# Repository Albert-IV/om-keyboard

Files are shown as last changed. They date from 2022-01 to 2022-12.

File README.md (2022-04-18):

# Om Keyboard

Right now I'm iterating on a 34 key split that uses MX spacing horiontally and choc spacing vertically.  Uses the splay from the Absolem keyboard and the lowered thumb keys of the Draculad.  

# Photos
## Rev 1 Photos

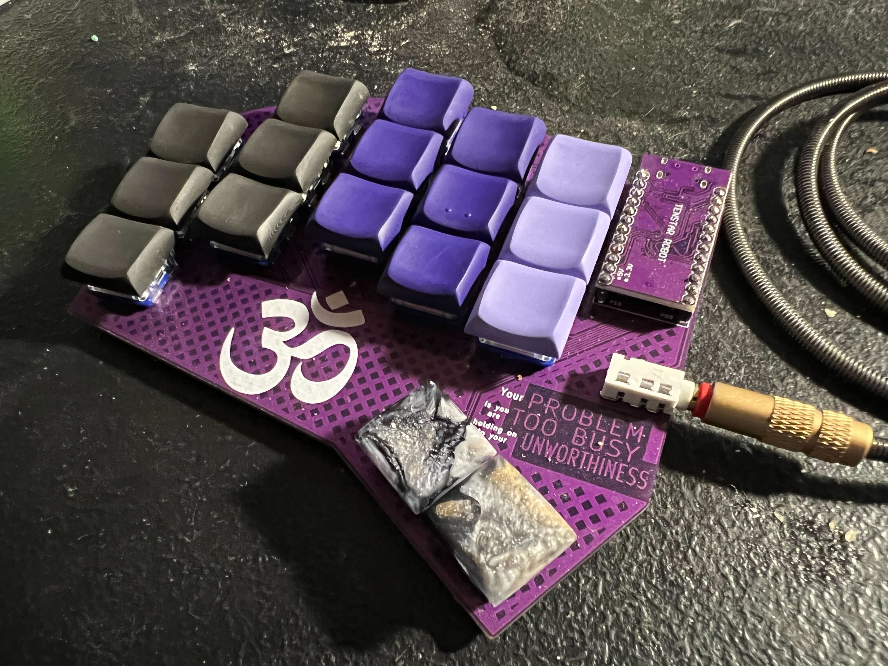
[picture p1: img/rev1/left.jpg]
Left Side


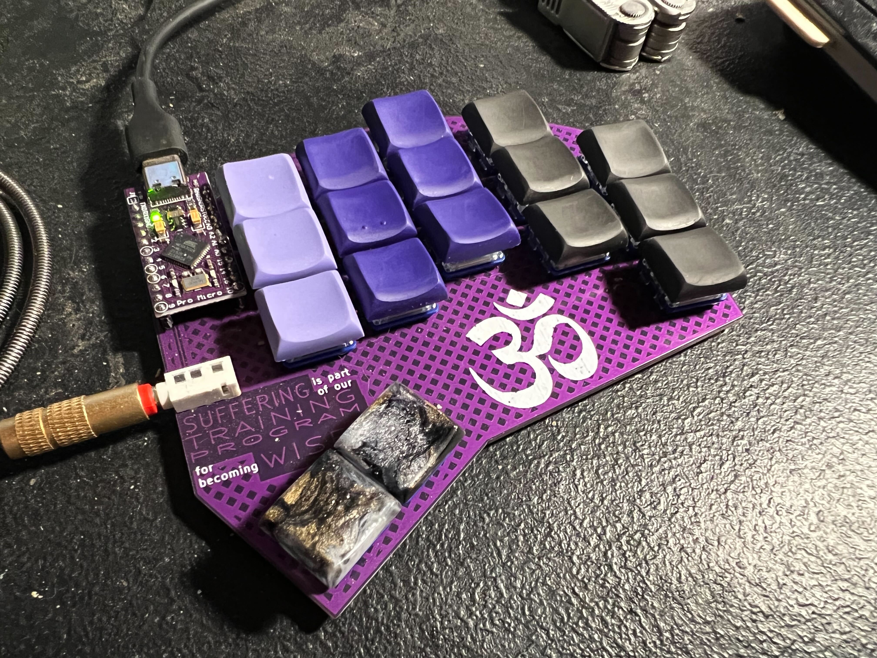
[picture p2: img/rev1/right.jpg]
Right Side


## Rev 0 Photos

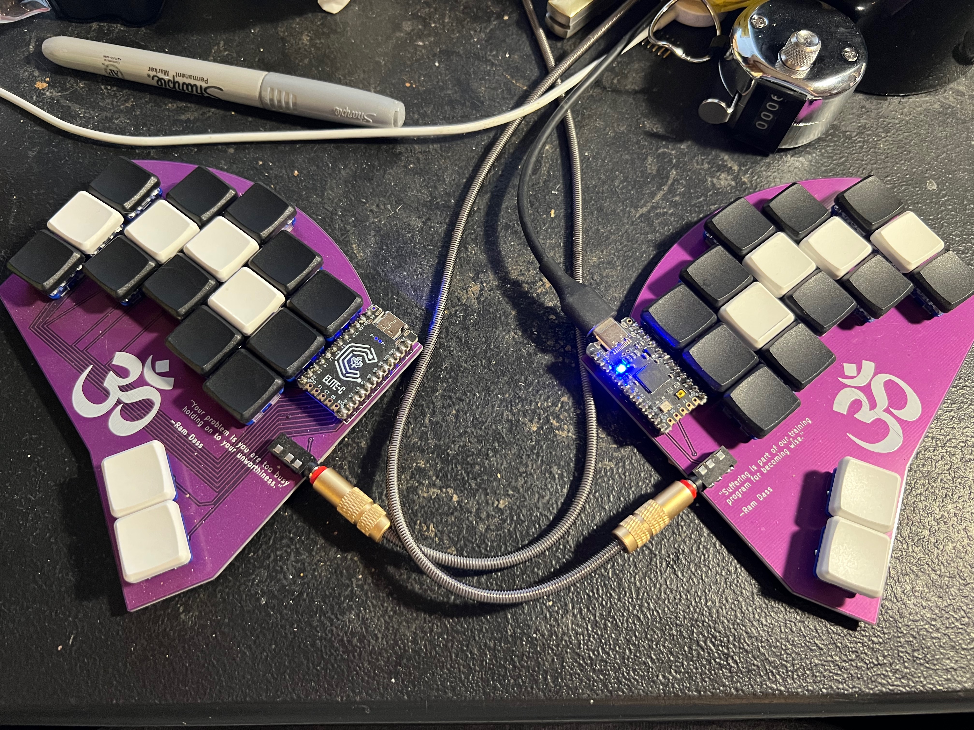
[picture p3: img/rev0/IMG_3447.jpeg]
MBK Build


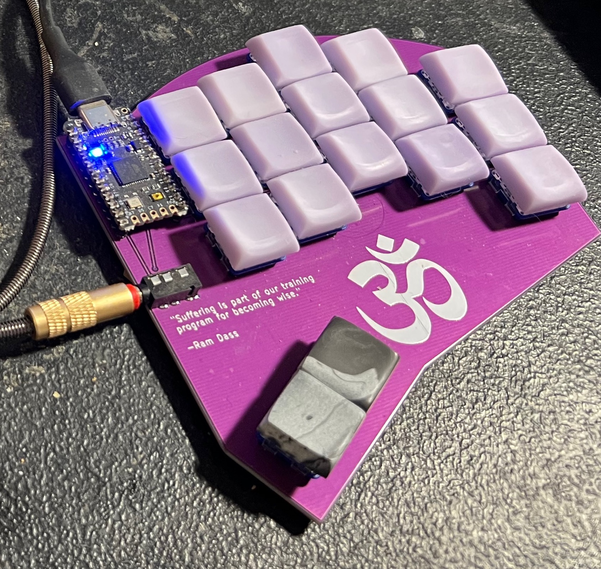
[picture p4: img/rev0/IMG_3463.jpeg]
Build with purple CS caps


# Notes

## Rev 1
Rev 0 was a pretty good success, though there are other tweaks that need to be made.  

Pinkies were not staggered enough I've found after trying out the Osprette keyboard.  The Osprette features a home pinky location that's equal to the bottom key of the ring finger and feels really comfortable / right.  Attempted to do the same for the pointer finger keys, however with such advanced stagger could not comfortably reach the bottom inner column keys.  30-key keyboards maybe have a point?

Additionally wanted to change the location of the ring finger as well.  Right now my ring finger naturally wants to rest on the outer ridge of the ring finger home key.  To compensate, I moved the key about a third of a U over, increasing the spave to hopefully feel correct. Looking at the spacing, this begs for splay, but will save this for the next iteration for now.  

Lastly I wanted to change the thumbs a _touch_ though not a ton as they felt pretty good.  I do feel like they may be a little low, but possibly not.  With MBK profile keycaps the thumbs weren't ultra comfortable, but once moved to CS felt great.  Actuating the key leverages the top joint of your thumb rather than the thumb tip, which for some may be optimal.  I chew my fingers a lot, so avoiding having to actuate with the side of my thumb nail where there may be hangnails is a feature, not a bug.

I still did move the thumbs up a touch.  Just a smidge.  It's hard to tell, as I had a key incorrectly placed inside my Ergogen config that made thumb positioning unreliable and reliant on other keys locations.  Future iterations will have a corrected config which will be rock solid, but for now I eyeballed positioning and hope it works out.  I do want to play with thumb rotation, but I'm unsure how to measure that.  When using arm rests my thumb arc looks one way, and while resting on the table the thumbs arc in a slightly different line.  May want to use some combination of the two?  Not sure.

Next iteration will leverage cardboard cutouts, so that I can put in switches and test drive on next layout iteration to fully dial in positioning.  Overall rev0 did feel comfortable, but not 100% perfect. I may play with an Osprette-like pinky cluster in the future, bumping the key count to 36 keys temporarily.

## Rev 0
Initial prototype using 34 keys, choc spacing vertically and MX spacing horizontally with a deep thumb a la Draculad and a touch of splay stolen from the Absolum.

PCB's were ordered from JLCPCB and built roughly Feb 23-24th 2022.  Used as a daily driver for about a month before making iterations for Rev 1

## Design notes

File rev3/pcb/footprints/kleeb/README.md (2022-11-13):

# Kleeb

This is a collection of the Kicad symbols, footprints and 3D models useful in keyboard creation other than normal mechanical switches and the ones included in Kicad's standard library, all in 6.0 format. I didn't create all of them, and some come from either other people on Discord, or from other online resources that isn't in a Git tree. Putting them in a centralized place means it's easier for people to use, distribute*, and compare, and changes can be made in a clearer way. I'll try to list the sources down below, but due to the nature of the sources they maybe incorrect/missing. If you have a problem with how I'm using/distributing them please let me know.

## License

Those directly created by me is licensed under MIT. Those came from Discord are technically in a grey zone, as they are shared without a (explicit) license. For those that came from other sources, the original license should be used. I do not intend to claim ownership over them, and they are here so they can be easily included in future projects.

## Symbols

### `ic`

- `MCP23S08`: From @petejohanson, converted to 6.0. 8-bit SPI bidirectional I/O expander, missing from Kicad libray
- `MT25QL128ABA1ESE`: created by me. 128Mib/16MiB QSPI NOR flash
- `CMM4030D`: I2S microphone
- `TMP117`: I2C high accuracy temperature sensor
- `IS31FL3729`: 16x8 or 15x9 I2C LED matrix driver
- `MAX98357A`: I2S DAC amplifier

### `display`

- `eink-128x80`: created by me. [128x80 Eink from waveshare](https://www.waveshare.com/product/displays/1.02inch-e-paper-module.htm)
- `ILI9341`: created by me. ILI9341 module
- `LCD2.2"`: created by me. [2.2 in TFT LCD module from Adafruit](https://www.adafruit.com/product/1480)
- `OLED-128x32`: created by me. Classic 128x32 OLED module [Example](https://www.littlekeyboards.com/collections/oled-screens/products/oled-screen)
- `OLED-128x64`: created by me. 128x64 OLED module [Example](https://www.littlekeyboards.com/collections/oled-screens/products/128x64-oled-screen)
- `adafruit-sharp-memory-display`: created by me. [Adafruit 1.3in SHARP memory display module](https://www.adafruit.com/product/3502)
- `adafruit-sharp-memory-display-no-useless`: created by me. Same as above but without non-necessary pins
- `TM022HDH26`: created by me. [2.2in raw SPI TFT LCD module](https://www.aliexpress.com/item/32417585937.html)

### `ic`

- `CMM4030D`, `eTQFP-32_7x7mm_P0.8mm`: created by me from datasheet

### `switch`

- `SKRHA`: created by me. [5-way joystick from Alps](https://www.mouser.com/ProductDetail/Alps-Alpine/SKRHAAE010?qs=6EGMNY9ZYDQQG43X8RE8sg%3D%3D)
- `diode-choc`: created by me. Originally taken from [@PJE66](https://github.com/PJE66), but with some of the pins hidden as they are not needed for external connections. Even though they are still 2 pin "components", the diode is included for clarity in the schematics, and should be used with the autogenerated choc footprints.

### `mcu`

- `holyiot-18010`: From someone else on Discord, but modified by me. [Holyiot 18010 nRF52840 BLE module](https://www.aliexpress.com/i/32868002366.html)
- `holyiot-18010-no-underside`: Same as above, but without underside pads
- `xiao`: created by me, merged from the `xiao` repo. The [Xiao controller](https://www.seeedstudio.com/Seeeduino-XIAO-Arduino-Microcontroller-SAMD21-Cortex-M0+-p-4426.html) from Seeed Studio.
- `xiao-ble`: Same as above. The [Xiao BLE controller](https://www.seeedstudio.com/Seeed-XIAO-BLE-nRF52840-p-5201.html) from Seeed Studio.
- `rp2040-zero`: created by me. The [RP2040 Zero controller](https://www.waveshare.com/rp2040-zero.htm) by WaveShare.
- `ms88sf3-nrf52840`, `ms88sf3-nrf52840-split`: From @Kurtis on Discord, who used a split symbol. I merged the ground pins and merged the units for the symbols, and corrected the footprint according to the datasheet, also making the keepout 5mm wide.

## Footprints

### `display`

- `LCD2.2in`: created by me.
- `OLED-128x32`: created by me.
- `OLED-128x32-cutout`: Same as above, but show the display area. Data came from `@rain` on Discord
- `OLED-128x32-double-sided`: Same as above, but has jumpers on both sides allowing the OLED to be installed on both sides. The jumpers on the reverse side of the display are to be soldered.
- `OLED-128x64`: created by me.
- `TM022HDH26`: created by me. Holes follow the positions on datasheet, pads are measured data
- `TM022HDH26_back`: Same as above, but pads are on the different side of PCB
- `adafruit-sharp-memory-display-1.3in`: From someone on Discord, modified by me
- `adafruit-sharp-memory-display-1.3in-no-mounting`: Same as above
- `adafruit-sharp-memory-display-1.3in-no-mounting-no-useless`: Same as above

### `mcu`

- `holyiot-18010`: Probably from someone on Discord, modified by me. [Holyiot 18010 nRF52840 BLE module](https://www.aliexpress.com/i/32868002366.html)
- `holyiot-18010-no-underside`: Same as above
- `xiao-smd`: created by me, merged from the `xiao` repo. The Xiao controller with SMD pads, with throughole pads for the 4 underside pads.
- `xiao-tht`: Same as above. The Xiao controller with THT pads, with throughole pads for the 4 underside pads.
- `xiao-ble-smd`: Same as above. The Xiao BLE controller with SMD pads, with throughole pads for the 4 pads under USB-C connector, 2 battery pads, and 2 NFC pads.
- `xiao-ble-tht`: Same as above. The Xiao BLE controller with THT pads, with throughole pads for the 4 pads under USB-C connector, 2 battery pads, and 2 NFC pads.
- `xiao-ble-tht-cutout`: Same as above. The Xiao BLE controller with THT pads, with throughole pads for the 4 pads under USB-C connector, 2 battery pads, and 2 NFC pads, except there are cutouts around the underside pads, so that one can cut around the pads making it easier to solder those pads.
- `rp2040-zero-smd`: created by me. The RP2040 Zero controller by WaveShare, with SMD pads and a cutout for the MCU itself.
- `rp2040-zero-tht`: Same as above. The RP2040 Zero controller, with THT pads and a cutout for the MCU itself.
- `rp2040-zero-smd-pads` and `rp2040-zero-tht-pads`: ___Experimental!___ Same as above, plus throughole pads to solder underside pads.
- `rp2040-zero-smd-pads-cutout` and `rp2040-zero-tht-pads-cutout`: ___Experimental!___ Same as above, but the pads can be made into castellated ones by cutting through the pads?

### `misc`

- `BA1AAAPC`: [From Digikey](https://www.digikey.com/en/products/detail/mpd-memory-protection-devices/BA1AAAPC/8119216). Low profile AAA battery holder
- `auklet-cover-mount`: created by me. Cover mounting positions for the Auklet steno board
- `auklet-mount`: created by me. Bottom screw hole mounting positions for the Auklet steno board
- `batwings`: created by me. The original batwings logo converted from some picture on the web
- `crides-pos`: created by me. The logo for `crides`
- `crides-neg`: Same as above, but inverted
- `debug-port`: created by me. For use with pogo pin clamp for SWD debug
- `debug-port-single-side`: Same as above, but only top side has solder mask
- `embedded`: created by me. The embedded steno logo
- `hirose-df30fb-20ds-0.4v(82)`: probably from Digikey
- `CMS1609`: created by me from datasheet
- `molex-503182-1852`: probably from DigiKey

### `switch`

- `SKRHA-boss`: created by me, following datasheet from Alps
- `SKRHA-no-boss`: same as above
- `switch-MSK-12C02-smd`: Not sure where from
- `EVQWGD001`: Fetched from `@darryldh` on Discord, not sure of origin

### `pg1350`, `pg1232` and `pg1425`

These footprints are autogenerated with python scripts cuz I hate hand making all the variants I need for choc. It uses [my fork of kicad-footprint-generator](https://github.com/crides/kicad-footprint-generator). The changes in the generator are basically usability changes for myself, and you'll see why in the diff.

The pg1350 footprint dimensions (i.e. pin sizes & locations) is originally taken from [Keebio](https://github.com/keebio/Keebio-Parts.pretty), the pg1232 ones from [here](https://github.com/tamanishi/Kailh_PG1232), and the pg1425 ones from [Kailh documentation](https://github.com/keyboardio/keyswitch_documentation/blob/master/datasheets/Kailh/CPG142501D02.pdf). They are converted to Python and modifications are added.

The outline on `User.Comments` is the outline of the side tabs, and the one on `User.Drawings` is slightly outside of the outline of the keycap, reflecting the spacing.

All of the footprints are auto generated now. Different letters signify different variations.
- `D`: includes diode in the footprint. It uses choc LED hole for (optional) SOD-123 diode placement, and the internal connections are already made. The center of the footprint is placed on the center of the diode to help with PCBA, and it's meant to be used with the custom symbol signifying that it has a builtin diode; 
- `R`: footprint is reversible. Througholes are included for both sides, another pad is used to connect the duplicated hole, and vias are used inside of the diode pads to connect the diodes on both sides, and silkscreens are duplicated on both sides;

All the following variants are spacing variants, which is useless for most people and I keep it here for my own sake.

- `S`: shorter spacing, only affects the cap outline. To be used with 15mm vertical spacing. This as close vertical as chocs gets without modding the switch itself;
- `SS`: "Super Short": even shorter spacing, only affects the cap outline. To be used with 13.5mm vertical spacing. This as close vertical as choc minis (pg1232) gets without modding the switch itself;
- `L` & `R`: only when used with `SS`; off centered spacing for use with same finger double column (e.g. most commonly the 2 columns for index finger, or columns for pinky).
- `N`: only when used with `SS`; as narrow as possible (14.5mm; or is the intersection of the `L` and `R` variants)

## Models

- `adafruit-sharp-memory-display`: Obtained from @petejohanson on Discord, not sure of creator
- `adafruit-sharp-memory-display-no-mounting`: As above, but edited to cut off mounting screw holes
- `BA1AAAPC`: [From Digikey](https://www.digikey.com/en/products/detail/mpd-memory-protection-devices/BA1AAAPC/8119216). Low profile AAA battery holder
- `holyiot-18010`: From `@darryldh` on Discord
- `hro-type-c-31-m-12`: Not sure of source; I probably got it on Discord
- `MBK-1u`: [From `@darryldh` on Thingiverse](https://www.thingiverse.com/thing:4564253)
- `SKRHAD`: [From Alps](https://tech.alpsalpine.com/prod/e/html/multicontrol/switch/skrh/skrhace010.html)
- `OLED-128x32`: Not sure from where. Model for the 128x32 OLED displays
- `TF31-12S-0.5SH`: Not sure from where exactly, should be a manufactorer model. 0.5mm pitched 12pin FPC ZIF socket
- `JST-PH-S2B-R`: [From SnapEDA on Digikey](https://www.digikey.com/short/p1d9b87m). JST PH SMD 2pin connector, commonly used for batteries. [Product on Adafruit](https://www.adafruit.com/product/1769)
- `pg1350`, `pg1350-mbk`, `pg1232`, `pg1232-mbk`: created by me. pg1350 and pg1232 choc switch models with MBK 1u keycaps. The pg1350 model is taken directly from [here](https://grabcad.com/library/kailh-choc-low-profile-switch-1), and the MBK model from [here](https://www.thingiverse.com/thing:4564253/files). The pg1232 model is made by me through cutting and rejoining pieces of the pg1350 model, which should immitate the general model but is otherwise very janky. The joint choc and MBK models are simply the combinations of the switch models and the MBK model.
- `rp2040-zero`: From the low pro Discord from `@gerrycave` from WaveShare. _Giant_ model of the RP2040-Zero, recentered by me through FreeCAD.
- `EVQWGD001`: A copy of <https://grabcad.com/library/panasonic-evqwgd001-encoder-1#!>. Doesn't seem to match footprint
- `TM035035`: From @freznel on Discord, originated from Cirque.

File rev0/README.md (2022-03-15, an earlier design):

Initially this board started off as a repo called cockamamie before finding a theme.  This is why all the files are named this way.

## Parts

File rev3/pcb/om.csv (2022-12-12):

Source: | /Users/alberte/personal/om-keyboard/rev3/pcb/om.kicad_sch
Date: | Tuesday, November 22, 2022 at 09:42:19 PM
Tool: | Eeschema (6.0.8-1)-1
Generator: | /Applications/KiCad/KiCad.app/Contents/SharedSupport/plugins/bom_csv_grouped_by_value.py
Component Count: | 44
Individual Components:
Item | Qty | Reference(s) | Value | LibPart | Footprint | Datasheet | LCSC
 |  | C1 | 1uF | Device:C_Small | Capacitor_SMD:C_0603_1608Metric | ~
 |  | C2 | 1uF | Device:C_Small | Capacitor_SMD:C_0603_1608Metric | ~
 |  | C3 | 4.7n | Device:C_Small | Capacitor_SMD:C_0805_2012Metric | ~
 |  | D1 | D_Schottky | Device:D_Schottky | Diode_SMD:D_SOD-323 | ~
 |  | D2 | Blue LED | Device:LED | LED_SMD:LED_0603_1608Metric | ~
 |  | D3 | Red LED | Device:LED | LED_SMD:LED_0603_1608Metric | ~
 |  | ESD1 | USBLC6-2P6 | Power_Protection:USBLC6-2P6 | Package_TO_SOT_SMD:SOT-666 | https://www.st.com/resource/en/datasheet/usblc6-2.pdf
 |  | J1 | USB_C_Receptacle | Connector:USB_C_Receptacle_USB2.0 | keebio-parts:USB-C-12-Pin-MidMount | https://www.usb.org/sites/default/files/documents/usb_type-c.zip
 |  | J2 | JST-BATT | Connector:Conn_01x02_Female | Connector_JST:JST_PH_S2B-PH-K_1x02_P2.00mm_Horizontal | ~
 |  | J4 | SWD | Connector:Conn_01x04_Female | Connector_PinSocket_2.00mm:PinSocket_1x04_P2.00mm_Vertical | ~
 |  | Q1 | AO3407 | Transistor_FET:AO3401A | Package_TO_SOT_SMD:SOT-23 | http://www.aosmd.com/pdfs/datasheet/AO3401A.pdf
 |  | Q2 | AO3407 | Transistor_FET:AO3401A | Package_TO_SOT_SMD:SOT-23 | http://www.aosmd.com/pdfs/datasheet/AO3401A.pdf
 |  | R1 | 100K | Device:R_Small | Resistor_SMD:R_0603_1608Metric | ~
 |  | R2 | 1M | Device:R_Small | Resistor_SMD:R_0603_1608Metric | ~
 |  | R3 | 2M | Device:R_Small | Resistor_SMD:R_0603_1608Metric | ~
 |  | R4 | 5.1K | Device:R_Small | Resistor_SMD:R_0603_1608Metric | ~
 |  | R5 | 5.1K | Device:R_Small | Resistor_SMD:R_0603_1608Metric | ~
 |  | R6 | 806/820k | Device:R_Small | Resistor_SMD:R_0603_1608Metric | ~
 |  | R7 | 2M | Device:R_Small | Resistor_SMD:R_0603_1608Metric | ~
 |  | R8 | 1K | Device:R_Small | Resistor_SMD:R_0603_1608Metric | ~
 |  | R9 | 1K | Device:R_Small | Resistor_SMD:R_0603_1608Metric | ~
 |  | R10 | 10K | Device:R_Small | Resistor_SMD:R_0603_1608Metric | ~
 |  | R_TACT1 | SW_Push | Switch:SW_Push | om-footprints:SKHLLCA010 | ~
 |  | SW1 | Choc | kleeb-switches:diode-choc | kleeb-pg1350:pg1350-DR
 |  | SW2 | Choc | kleeb-switches:diode-choc | kleeb-pg1350:pg1350-DR
 |  | SW3 | Choc | kleeb-switches:diode-choc | kleeb-pg1350:pg1350-DR
 |  | SW4 | Choc | kleeb-switches:diode-choc | kleeb-pg1350:pg1350-DR
 |  | SW5 | Choc | kleeb-switches:diode-choc | kleeb-pg1350:pg1350-DR
 |  | SW6 | Choc | kleeb-switches:diode-choc | kleeb-pg1350:pg1350-DR
 |  | SW7 | Choc | kleeb-switches:diode-choc | kleeb-pg1350:pg1350-DR
 |  | SW8 | Choc | kleeb-switches:diode-choc | kleeb-pg1350:pg1350-DR
 |  | SW9 | Choc | kleeb-switches:diode-choc | kleeb-pg1350:pg1350-DR
 |  | SW10 | Choc | kleeb-switches:diode-choc | kleeb-pg1350:pg1350-DR
 |  | SW11 | Choc | kleeb-switches:diode-choc | kleeb-pg1350:pg1350-DR
 |  | SW12 | Choc | kleeb-switches:diode-choc | kleeb-pg1350:pg1350-DR
 |  | SW13 | Choc | kleeb-switches:diode-choc | kleeb-pg1350:pg1350-DR
 |  | SW14 | Choc | kleeb-switches:diode-choc | kleeb-pg1350:pg1350-DR
 |  | SW15 | Choc | kleeb-switches:diode-choc | kleeb-pg1350:pg1350-DR
 |  | SW16 | Choc | kleeb-switches:diode-choc | kleeb-pg1350:pg1350-DR
 |  | SW17 | Choc | kleeb-switches:diode-choc | kleeb-pg1350:pg1350-DR
 |  | SW_POW1 | SW_SPDT | Switch:SW_SPDT | Button_Switch_SMD:SW_SPDT_PCM12 | ~
 |  | U1 | nRF52840_holyiot_18010 | kleeb-mcu:holyiot-18010 | kleeb-mcu:holyiot-18010 | http://www.holyiot.com/tp/2019042516322180424.pdf
 |  | U2 | XC6206P LDO | kicad-keyboard-parts:XC6206PxxxMR-Regulator_Linear | Package_TO_SOT_SMD:SOT-23 | https://www.torexsemi.com/file/xc6206/XC6206.pdf | C5446
 |  | U3 | LTC4054ES5-4.2 | Battery_Management:LTC4054ES5-4.2 | Package_TO_SOT_SMD:TSOT-23-5 | https://www.analog.com/media/en/technical-documentation/data-sheets/405442xf.pdf
Collated Components:
Item | Qty | Reference(s) | Value | LibPart | Footprint | Datasheet | LCSC
1 | 2 | C1, C2 | 1uF | Device:C_Small | Capacitor_SMD:C_0603_1608Metric | ~
2 | 1 | C3 | 4.7n | Device:C_Small | Capacitor_SMD:C_0805_2012Metric | ~
3 | 1 | D1 | D_Schottky | Device:D_Schottky | Diode_SMD:D_SOD-323 | ~
4 | 1 | D2 | Blue LED | Device:LED | LED_SMD:LED_0603_1608Metric | ~
5 | 1 | D3 | Red LED | Device:LED | LED_SMD:LED_0603_1608Metric | ~
6 | 1 | ESD1 | USBLC6-2P6 | Power_Protection:USBLC6-2P6 | Package_TO_SOT_SMD:SOT-666 | https://www.st.com/resource/en/datasheet/usblc6-2.pdf
7 | 1 | J1 | USB_C_Receptacle | Connector:USB_C_Receptacle_USB2.0 | keebio-parts:USB-C-12-Pin-MidMount | https://www.usb.org/sites/default/files/documents/usb_type-c.zip
8 | 1 | J2 | JST-BATT | Connector:Conn_01x02_Female | Connector_JST:JST_PH_S2B-PH-K_1x02_P2.00mm_Horizontal | ~
9 | 1 | J4 | SWD | Connector:Conn_01x04_Female | Connector_PinSocket_2.00mm:PinSocket_1x04_P2.00mm_Vertical | ~
10 | 2 | Q1, Q2 | AO3407 | Transistor_FET:AO3401A | Package_TO_SOT_SMD:SOT-23 | http://www.aosmd.com/pdfs/datasheet/AO3401A.pdf
11 | 1 | R1 | 100K | Device:R_Small | Resistor_SMD:R_0603_1608Metric | ~
12 | 1 | R2 | 1M | Device:R_Small | Resistor_SMD:R_0603_1608Metric | ~
13 | 2 | R3, R7 | 2M | Device:R_Small | Resistor_SMD:R_0603_1608Metric | ~
14 | 2 | R4, R5 | 5.1K | Device:R_Small | Resistor_SMD:R_0603_1608Metric | ~
15 | 1 | R6 | 806/820k | Device:R_Small | Resistor_SMD:R_0603_1608Metric | ~
16 | 2 | R8, R9 | 1K | Device:R_Small | Resistor_SMD:R_0603_1608Metric | ~
17 | 1 | R10 | 10K | Device:R_Small | Resistor_SMD:R_0603_1608Metric | ~
18 | 1 | R_TACT1 | SW_Push | Switch:SW_Push | om-footprints:SKHLLCA010 | ~
19 | 17 | SW1, SW2, SW3, SW4, SW5, SW6, SW7, SW8, SW9, SW10, SW11, SW12, SW13, SW14, SW15, SW16, SW17 | Choc | kleeb-switches:diode-choc | kleeb-pg1350:pg1350-DR
20 | 1 | SW_POW1 | SW_SPDT | Switch:SW_SPDT | Button_Switch_SMD:SW_SPDT_PCM12 | ~
21 | 1 | U1 | nRF52840_holyiot_18010 | kleeb-mcu:holyiot-18010 | kleeb-mcu:holyiot-18010 | http://www.holyiot.com/tp/2019042516322180424.pdf
22 | 1 | U2 | XC6206P LDO | kicad-keyboard-parts:XC6206PxxxMR-Regulator_Linear | Package_TO_SOT_SMD:SOT-23 | https://www.torexsemi.com/file/xc6206/XC6206.pdf | C5446
23 | 1 | U3 | LTC4054ES5-4.2 | Battery_Management:LTC4054ES5-4.2 | Package_TO_SOT_SMD:TSOT-23-5 | https://www.analog.com/media/en/technical-documentation/data-sheets/405442xf.pdf

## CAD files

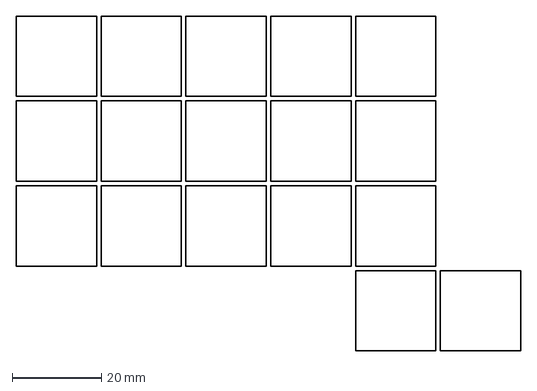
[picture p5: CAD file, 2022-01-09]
output/points/demo.dxf
113.0 x 75.0 mm

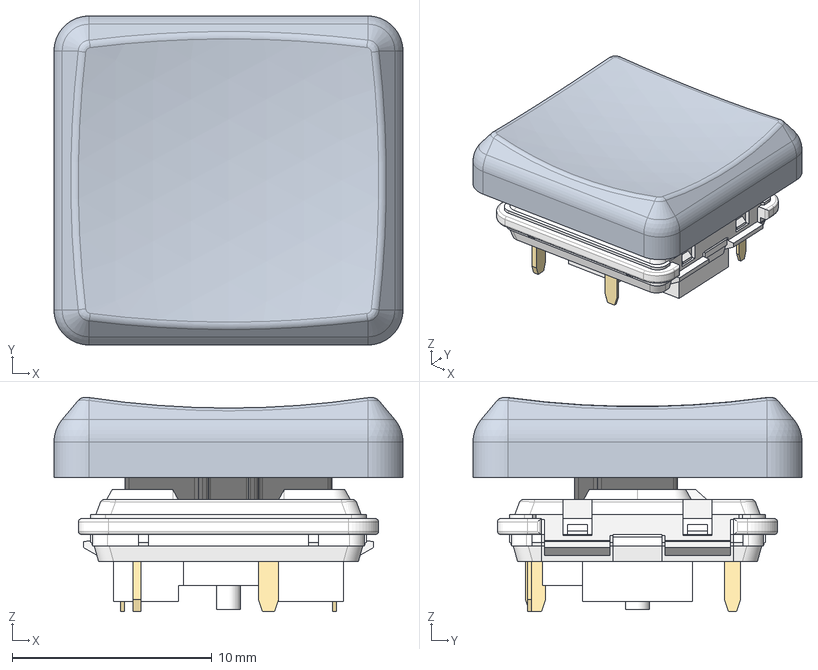
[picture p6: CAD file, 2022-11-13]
rev3/pcb/footprints/kleeb/models/pg1232-mbk.step
17.4 x 16.4 x 10.7 mm
Document x 3
(Unsaved)

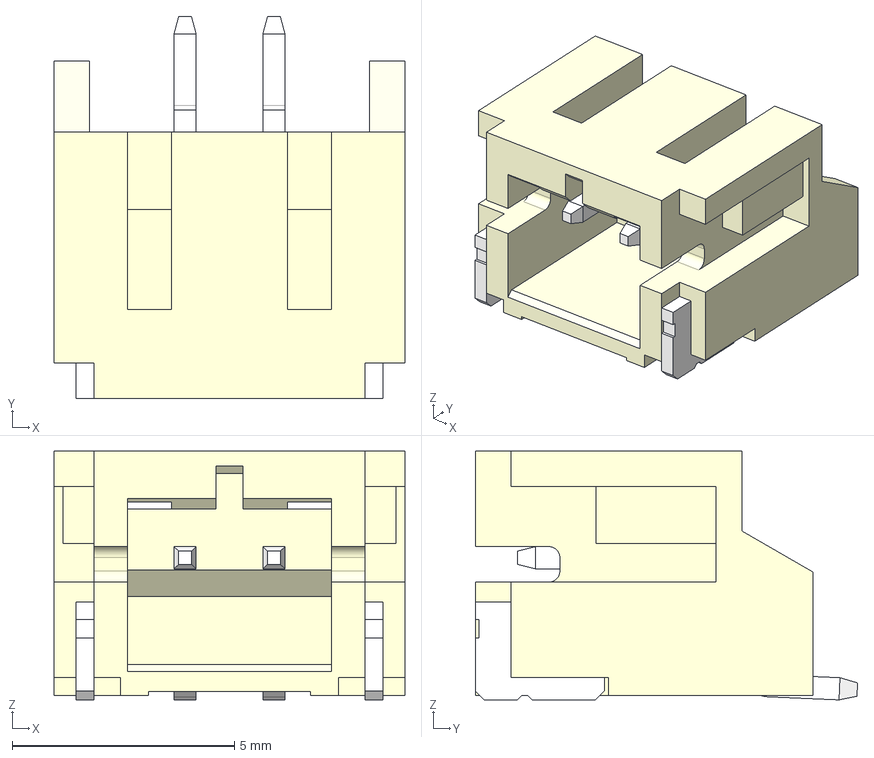
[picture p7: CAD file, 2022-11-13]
rev3/pcb/footprints/kleeb/models/JST-PH-S2B-R.step
7.90 x 8.60 x 5.60 mm

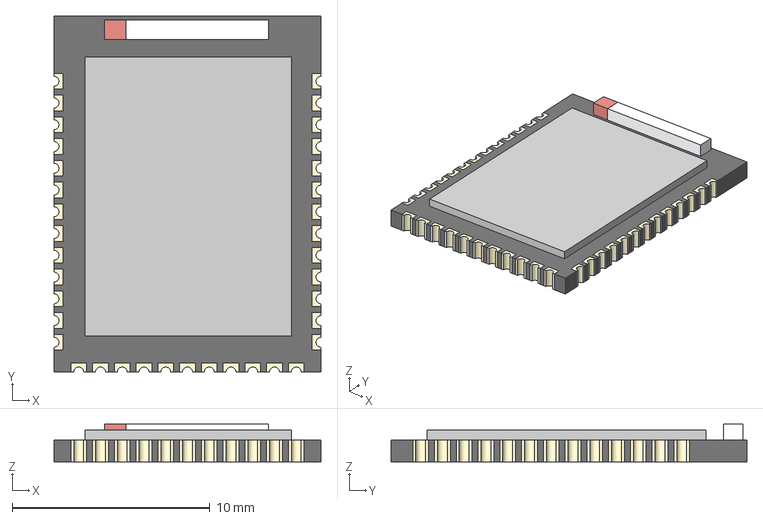
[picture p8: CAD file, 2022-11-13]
rev3/pcb/footprints/kleeb/models/holyiot-18010.step
13.5 x 18.0 x 1.92 mm

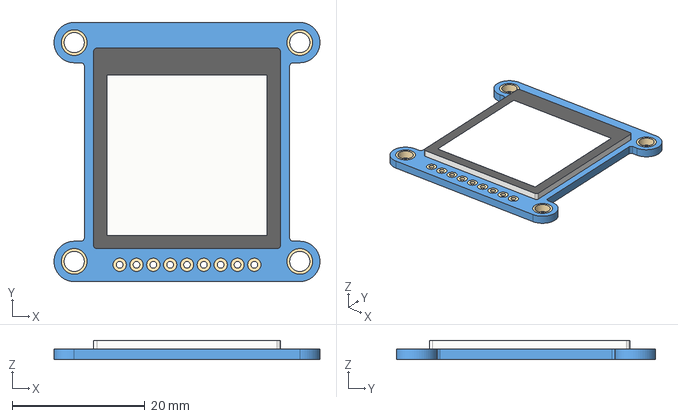
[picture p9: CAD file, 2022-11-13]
rev3/pcb/footprints/kleeb/models/adafruit-sharp-memory-display.step
40.1 x 39.1 x 2.91 mm

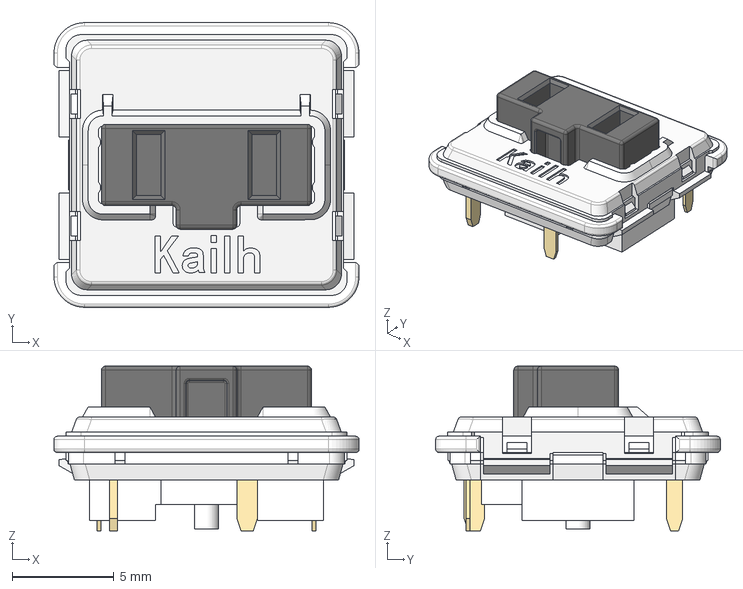
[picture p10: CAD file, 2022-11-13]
rev3/pcb/footprints/kleeb/models/pg1232.step
15.0 x 14.0 x 8.10 mm

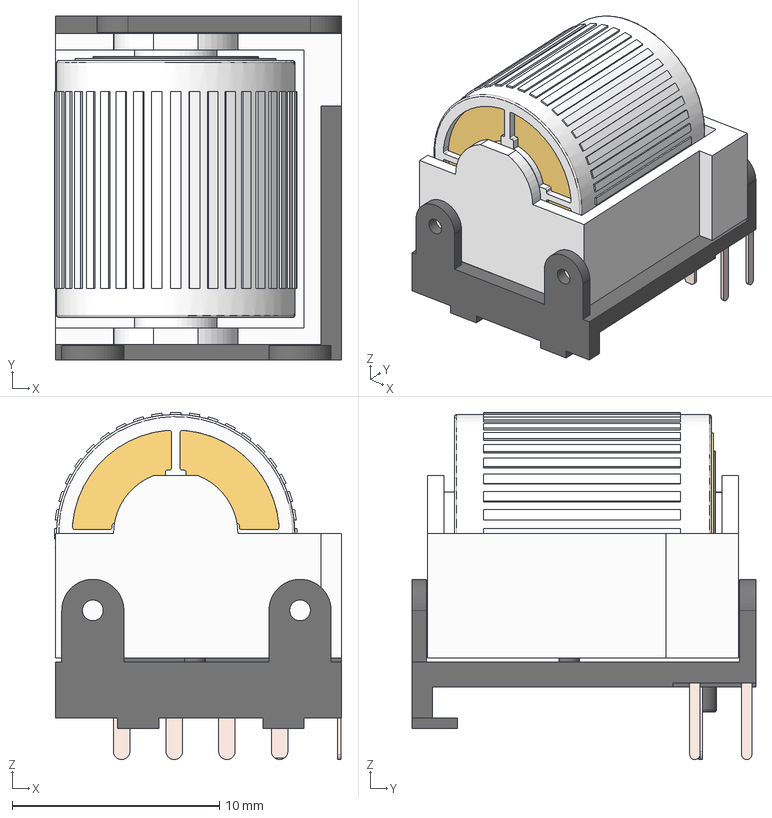
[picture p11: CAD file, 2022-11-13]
rev3/pcb/footprints/kleeb/models/EVQWGD001.step
13.9 x 16.6 x 16.8 mm
Plastic
Barrel in
Cap
Barrel out
Leg (1)
housing
Leg (2)
Leg (3)
Plastic (1)
Leg
Leg (4)
Leg (5)

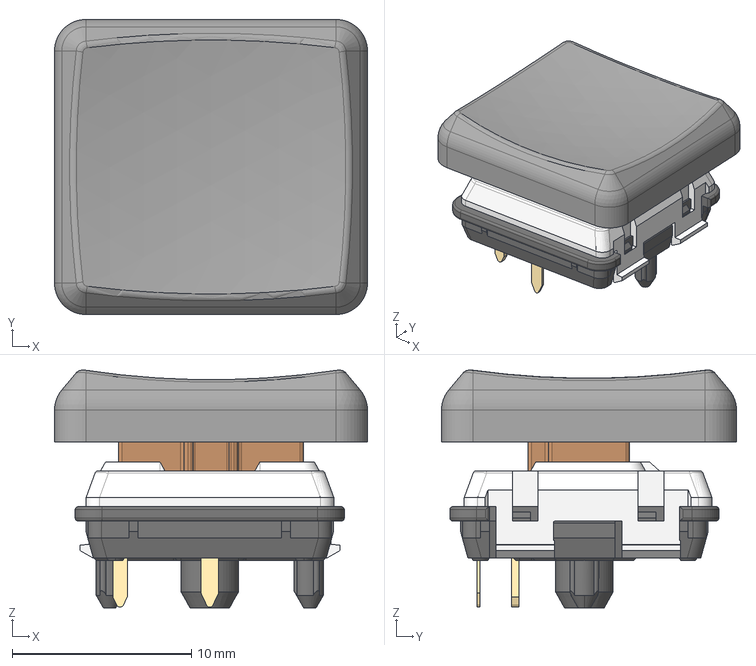
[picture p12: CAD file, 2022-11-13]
rev3/pcb/footprints/kleeb/models/pg1350-mbk.step
17.4 x 16.4 x 13.3 mm
(Unsaved)
Document x 5

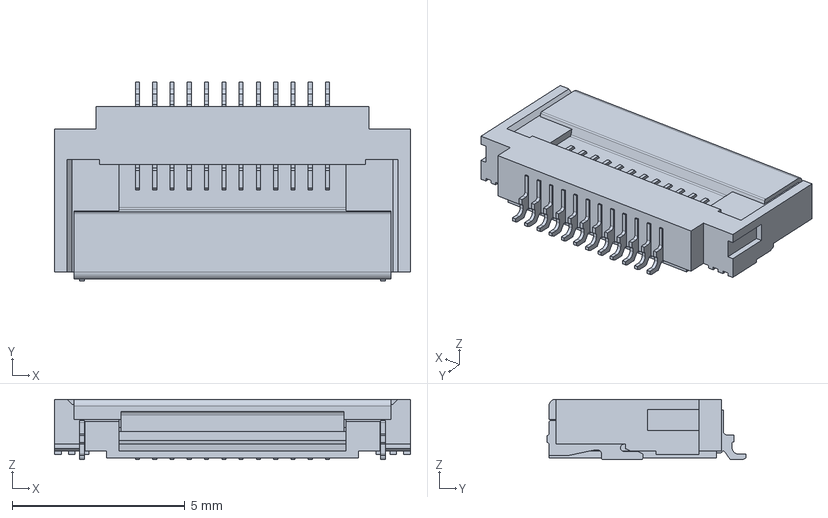
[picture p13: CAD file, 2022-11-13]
rev3/pcb/footprints/kleeb/models/TF31-12S-0.5SH.step
10.3 x 5.75 x 1.75 mm

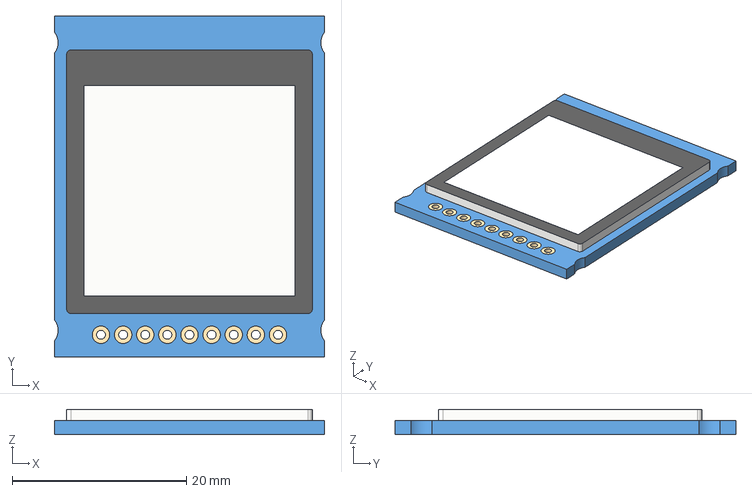
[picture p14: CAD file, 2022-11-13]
rev3/pcb/footprints/kleeb/models/adafruit-sharp-memory-display-no-mounting.step
31.0 x 39.1 x 2.91 mm
Adafruit Sharp Memory Display v4 x 12

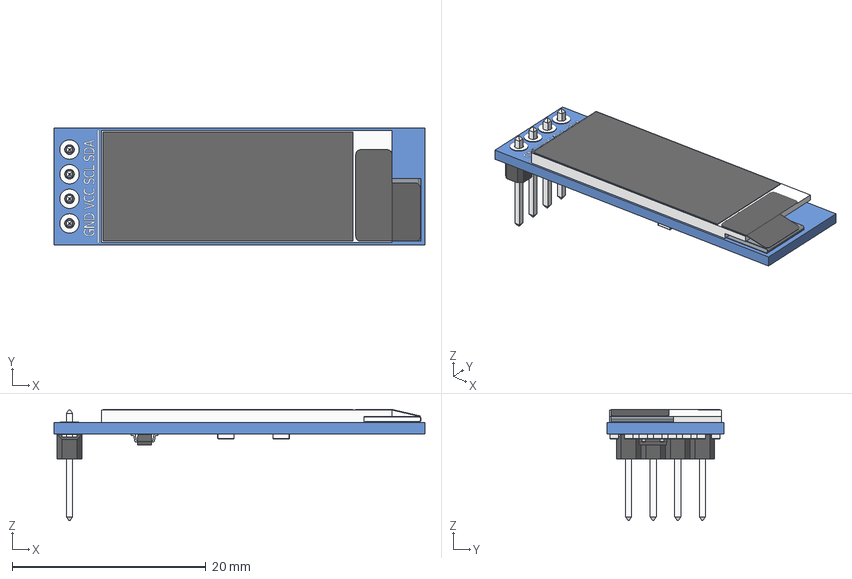
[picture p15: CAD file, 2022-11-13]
rev3/pcb/footprints/kleeb/models/OLED-128x32.step
38.3 x 12.1 x 11.5 mm
OLED_0.91_128x32
Pin Header 4 x 1 TH 2.54mm Pitch
RESC-0603 x 13
2SD0601A

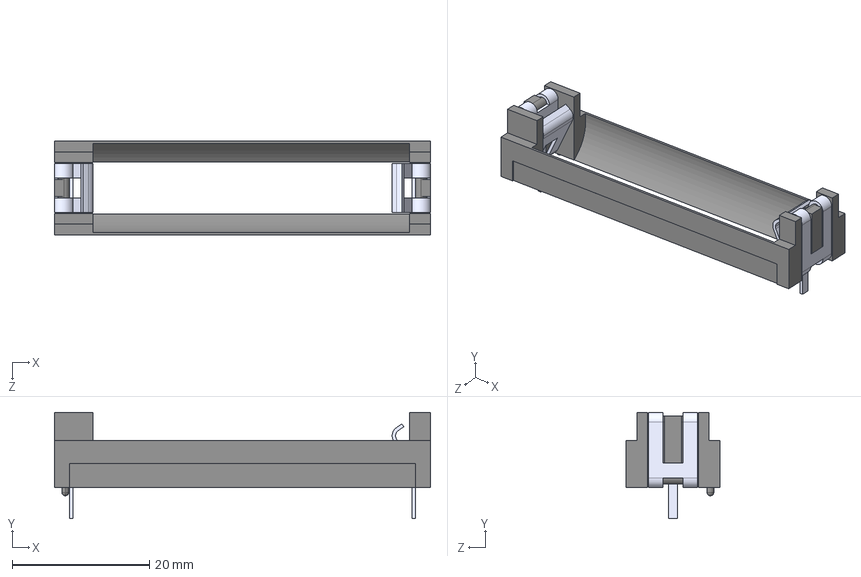
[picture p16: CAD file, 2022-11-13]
rev3/pcb/footprints/kleeb/models/BA1AAAPC.step
54.9 x 15.5 x 13.7 mm

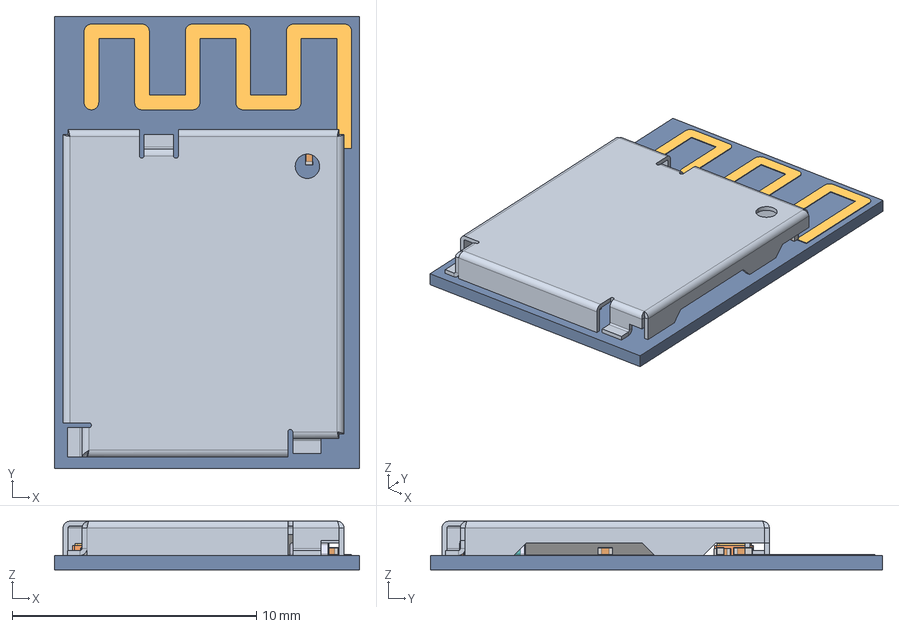
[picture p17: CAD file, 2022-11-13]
rev3/pcb/footprints/kleeb/models/MS88SF3.step
12.5 x 18.5 x 1.99 mm
Board
ANT-2.4G-16
Open_CASCADE_STEP_translator_6.8_9.1
Open_CASCADE_STEP_translator_6.8_9.2.1
pinShape x 184
2012crystal
epson2016
88sf3190624

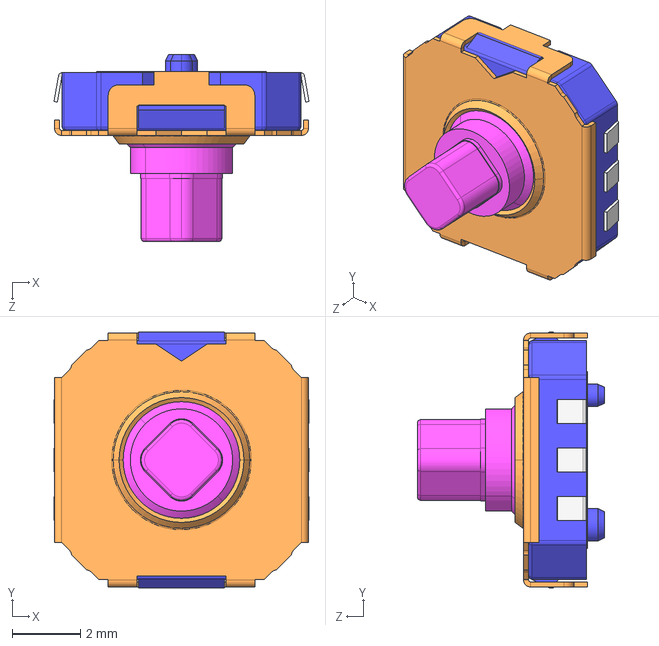
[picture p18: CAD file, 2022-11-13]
rev3/pcb/footprints/kleeb/models/SKRHAD.step
7.48 x 7.50 x 5.50 mm

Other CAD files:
rev3/pcb/footprints/kleeb/models/MBK-1u.step
rev3/pcb/footprints/kleeb/models/hro-type-c-31-m-12.step
rev3/pcb/footprints/kleeb/models/pg1350.step
rev2/full-case/bottom.dxf
rev2/full-case/top.dxf
rev2/tray-case/Om Rev 2 Case v1.stl
rev2/tray-case/Om Rev 2 Case v2.stl
rev2/tray-case/bottom-layout.dxf

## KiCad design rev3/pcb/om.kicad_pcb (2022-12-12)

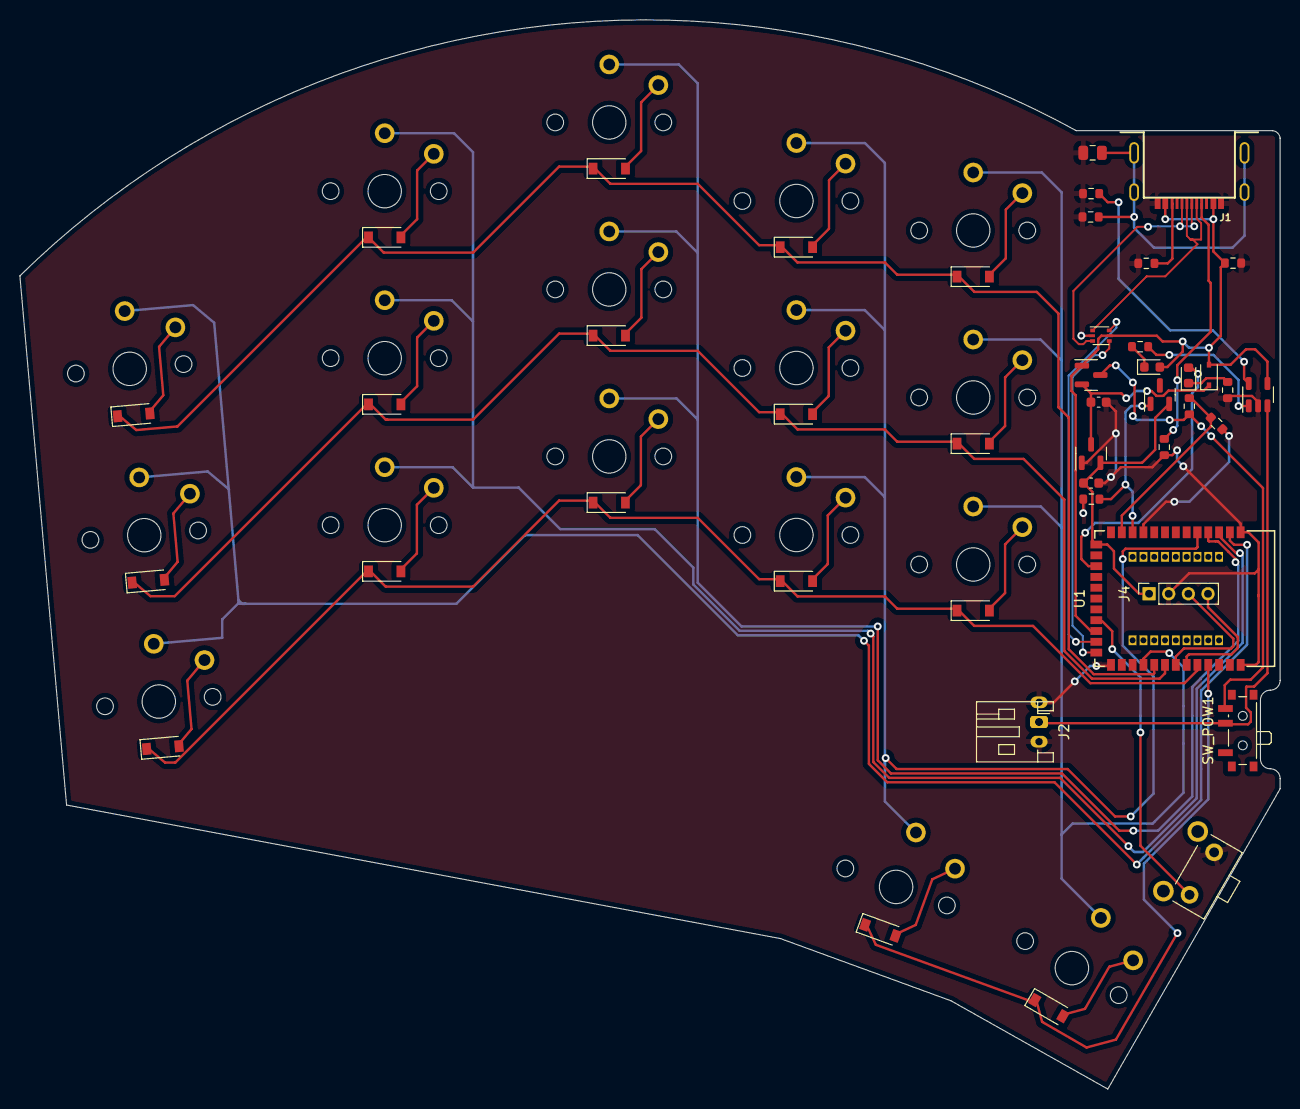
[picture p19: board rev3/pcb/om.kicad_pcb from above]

Board: 2 copper layers, 128.3 x 108.8 mm, 62 parts (1 on the bottom side), 50 nets.

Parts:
C1, C2: 1uF; C_0603_1608Metric
C3: 4.7n; C_0805_2012Metric
D1: D_Schottky; D_SOD-323
D2: Blue LED; LED_0603_1608Metric
D3: Red LED; LED_0603_1608Metric
DIODE1, DIODE2, DIODE3, DIODE4, DIODE5, DIODE6, DIODE7, DIODE8, DIODE9, DIODE10, DIODE11, DIODE12, DIODE13, DIODE14, DIODE15, DIODE16, DIODE17: 1N914WT; D_SOD-123
ESD1: USBLC6-2P6; SOT-666
J1: USB_C_Receptacle; USB-C-12-Pin-MidMount
J2, J3: JST-BATT; JST_PH_S2B-PH-K_1x02_P2.00mm_Horizontal
J4: SWD; PinSocket_1x04_P2.00mm_Vertical
Q1, Q2: AO3407; SOT-23
R1: 100K; R_0603_1608Metric
R2: 1M; R_0603_1608Metric
R3, R7: 2M; R_0603_1608Metric
R4, R5: 5.1K; R_0603_1608Metric
R6: 806/820k; R_0603_1608Metric
R8, R9: 1K; R_0603_1608Metric
R10: 10K; R_0603_1608Metric
R_TACT1: SW_Push; SKHLLCA010
SW1, SW2, SW3, SW4, SW5, SW6, SW7, SW8, SW9, SW10, SW11, SW12, SW13, SW14, SW15, SW16, SW17: Choc; pg1350
SW_POW1: SW_SPDT; SW_SPDT_PCM12
U1: nRF52840_holyiot_18010; holyiot-18010
U2: XC6206P LDO; SOT-23
U3: LTC4054ES5-4.2; TSOT-23-5

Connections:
+3V3: C2.1, J4.1, Q2.2 (S), U1.55 (VDD), U2.2 (VO)
+BATT: J2.1, J3.1 (2), SW_POW1.2 (B), U3.3 (BAT)
/BAT+_SWITCHED: Q1.3 (D), R6.1, SW_POW1.3 (C)
/Net-(U3-PROG): R10.2, U3.5 (PROG)
/V-IN: C1.1, D1.1 (K), Q1.2 (S), U2.3 (VI)
BLUE_LED: D2.2 (A), U1.53 (P1.09)
Col1: SW1.1, SW2.1, SW3.1, U1.2 ([L]_P1.11)
Col2: SW4.1, SW5.1, SW6.1, U1.3 ([L]_P1.10)
Col3: SW7.1, SW8.1, SW9.1, U1.4 ([L]_P1.13)
Col4: SW10.1, SW11.1, SW12.1, SW16.1, U1.5 ([L]_P1.15)
Col5: SW13.1, SW14.1, SW15.1, SW17.1, U1.41 ([L]_P1.03)
D+: ESD1.4 (I/O2), U1.45 (D+)
D-: ESD1.6 (I/O1), U1.46 (D-)
Earth: C3.2, J1.S1 (SHIELD), R2.2
GND: C1.2, C2.2, C3.1, ESD1.2 (GND), J1.A1 (GND), J2.2, J3.2 (1), J4.2, R1.2, R2.1, R3.2, R4.2, R5.2, R8.2, R10.1, R_TACT1.2, U1.1 (GND), U1.32 (GND), U1.44 (GND), U2.1 (GND), U3.2 (GND)
unnamed: D2.1 (K), R8.1
unnamed: D3.1 (K), R9.1
unnamed: DIODE1.2 (A), SW1.2
unnamed: DIODE3.2 (A), SW3.2
unnamed: DIODE4.2 (A), SW4.2
unnamed: DIODE5.2 (A), SW5.2
unnamed: DIODE6.2 (A), SW6.2
unnamed: DIODE7.2 (A), SW7.2
unnamed: DIODE8.2 (A), SW8.2
unnamed: DIODE9.2 (A), SW9.2
unnamed: DIODE10.2 (A), SW10.2
unnamed: DIODE12.2 (A), SW12.2
unnamed: J1.A5 (CC1), R5.1
unnamed: J1.B5 (CC2), R4.1
unnamed: R9.2, U3.1 (~CHRG)
unnamed: DIODE2.2 (A), SW2.2
unnamed: DIODE11.2 (A), SW11.2
unnamed: DIODE13.2 (A), SW13.2
unnamed: DIODE14.2 (A), SW14.2
unnamed: DIODE15.2 (A), SW15.2
unnamed: DIODE16.2 (A), SW16.2
unnamed: DIODE17.2 (A), SW17.2
RESET: R_TACT1.1, U1.48 (Reset/P0.18)
Row1: DIODE1.1 (K), DIODE4.1 (K), DIODE7.1 (K), DIODE10.1 (K), DIODE13.1 (K), U1.40 ([L]_P1.01)
Row2: DIODE2.1 (K), DIODE5.1 (K), DIODE8.1 (K), DIODE11.1 (K), DIODE14.1 (K), U1.39 ([L]_P1.02)
Row3: DIODE3.1 (K), DIODE6.1 (K), DIODE9.1 (K), DIODE12.1 (K), DIODE15.1 (K), U1.36 ([L]_P1.04)
Row4: DIODE16.1 (K), DIODE17.1 (K), U1.35 ([L]_P1.06)
SWDCLK: J4.3, U1.38 (SWC)
SWDIO: J4.4, U1.37 (SWD)
USBD+: ESD1.3 (I/O2), J1.A6 (D+), J1.B6 (D+)
USBD-: ESD1.1 (I/O1), J1.A7 (D-), J1.B7 (D-)
VBUS: D1.2 (A), D3.2 (A), ESD1.5 (VBUS), J1.A4 (VBUS), Q1.1 (G), R1.1, U1.47 (VBUS), U3.4 (VCC)
VCC_CONTROL: Q2.1 (G), R3.1, U1.11 ([L]_A7_P0.31)
VSENSE: R6.2, R7.1, U1.12 (A2_P0.04)
VSENSE_ENABLE: R7.2, U1.10 ([L]_A6_P0.30)

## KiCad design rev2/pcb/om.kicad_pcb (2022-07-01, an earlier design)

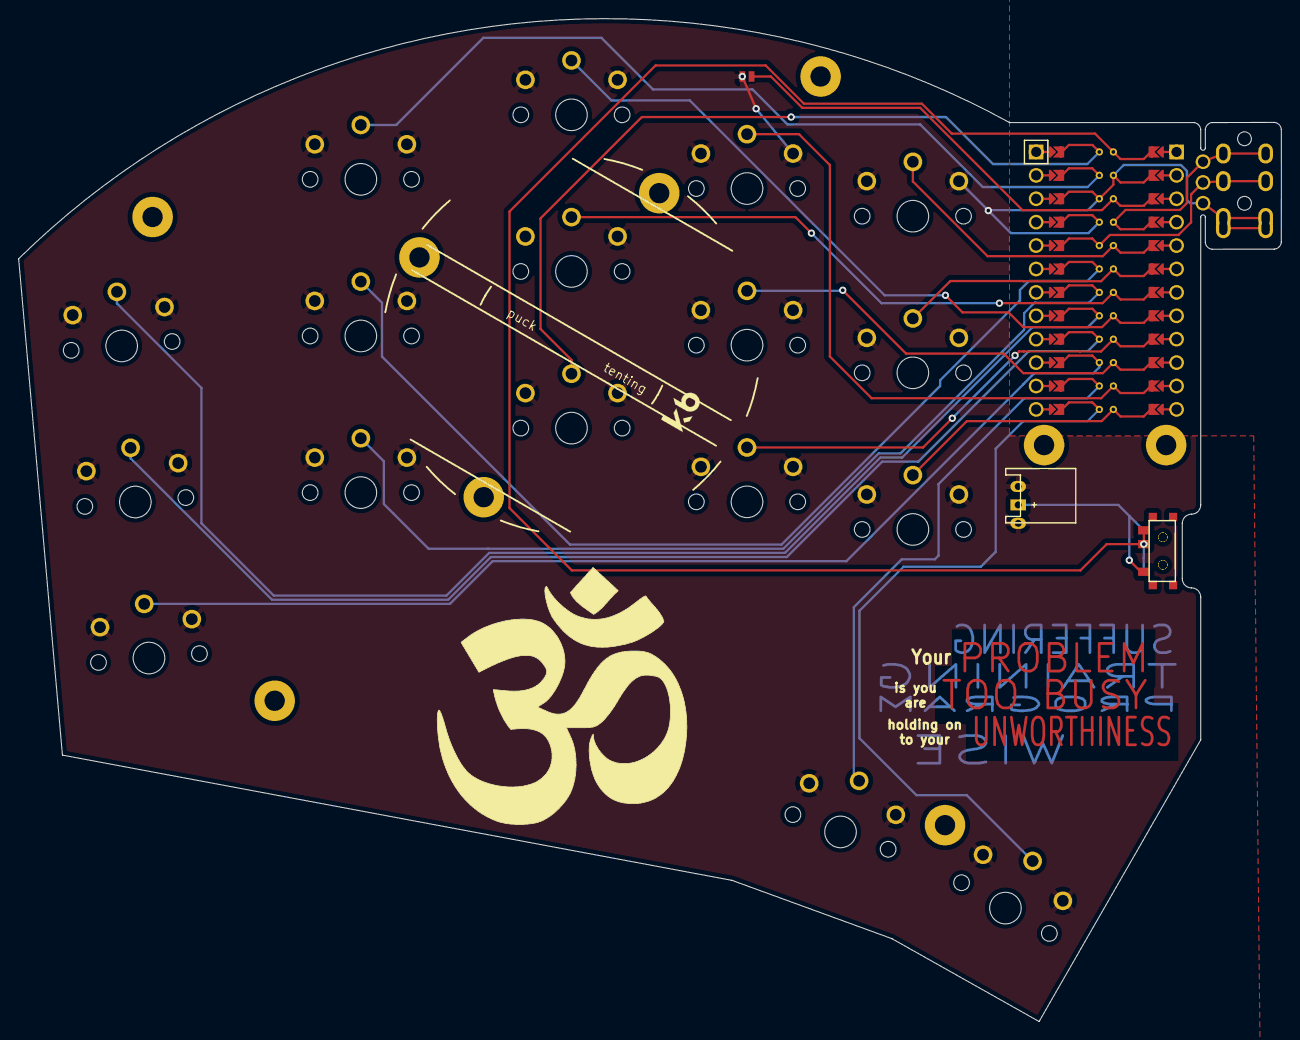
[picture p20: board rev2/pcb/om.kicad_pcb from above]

Board: 2 copper layers, 137.0 x 108.8 mm, 23 parts (1 on the bottom side), 21 nets.

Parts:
J1: Jumper
JST1: JST_PH_S2B-PH-K_02x2.00mm_Angled
MCU1: ProMicro
S1, S2, S3, S4, S5, S6, S7, S8, S9, S10, S11, S12, S13, S14, S15, S16, S17: PG1350
T1, T1#2: SPDT_C128955
_1: Tenting Puck

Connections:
GND: J1.1, JST1.1, JST1.2, MCU1.2, MCU1.21, MCU1.22, S1.1, S2.1, S3.1, S4.1, S5.1, S6.1, S7.1, S8.1, S9.1, S10.1, S11.1, S12.1, S13.1, S14.1, S15.1, S16.1, S17.1
P0: MCU1.23, S6.2
P1: MCU1.24, S7.2
P3: MCU1.19, S5.2
P4: MCU1.18, S4.2
P5: MCU1.17, S3.2
P6: MCU1.16, S2.2
P7: MCU1.15, S1.2
P8: MCU1.14, S16.2
P9: MCU1.13, S17.2
P10: MCU1.12, S13.2
P14: MCU1.10, S11.2
P15: MCU1.9, S10.2
P16: MCU1.11, S12.2
P18: MCU1.8, S9.2
P19: MCU1.7, S8.2
P20: MCU1.6, S14.2
P21: MCU1.5, S15.2
POSITIVE: JST1.1, T1.1, T1#2.1
RAW: MCU1.1, T1.2, T1.3, T1#2.2, T1#2.3
RST: J1.2, MCU1.3

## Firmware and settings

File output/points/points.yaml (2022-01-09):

matrix_pinky_bottom:
    x: 0
    'y': 0
    r: 0
    meta:
        shift:
            - 0
            - 0
        rotate: 0
        padding: 19
        width: 1
        height: 1
        skip: false
        asym: both
        name: matrix_pinky_bottom
        colrow: pinky_bottom
        col: &ref_0
            stagger: 0
            spread: 0
            rotate: 0
            origin:
                - 0
                - 0
            rows: {}
            key: {}
            name: pinky
        row: bottom
matrix_pinky_home:
    x: 0
    'y': 19
    r: 0
    meta:
        shift:
            - 0
            - 0
        rotate: 0
        padding: 19
        width: 1
        height: 1
        skip: false
        asym: both
        name: matrix_pinky_home
        colrow: pinky_home
        col: *ref_0
        row: home
matrix_pinky_top:
    x: 0
    'y': 38
    r: 0
    meta:
        shift:
            - 0
            - 0
        rotate: 0
        padding: 19
        width: 1
        height: 1
        skip: false
        asym: both
        name: matrix_pinky_top
        colrow: pinky_top
        col: *ref_0
        row: top
matrix_ring_bottom:
    x: 19
    'y': 0
    r: 0
    meta:
        shift:
            - 0
            - 0
        rotate: 0
        padding: 19
        width: 1
        height: 1
        skip: false
        asym: both
        name: matrix_ring_bottom
        colrow: ring_bottom
        col: &ref_1
            stagger: 0
            spread: 19
            rotate: 0
            origin:
                - 0
                - 0
            rows: {}
            key: {}
            name: ring
        row: bottom
matrix_ring_home:
    x: 19
    'y': 19
    r: 0
    meta:
        shift:
            - 0
            - 0
        rotate: 0
        padding: 19
        width: 1
        height: 1
        skip: false
        asym: both
        name: matrix_ring_home
        colrow: ring_home
        col: *ref_1
        row: home
matrix_ring_top:
    x: 19
    'y': 38
    r: 0
    meta:
        shift:
            - 0
            - 0
        rotate: 0
        padding: 19
        width: 1
        height: 1
        skip: false
        asym: both
        name: matrix_ring_top
        colrow: ring_top
        col: *ref_1
        row: top
matrix_middle_bottom:
    x: 38
    'y': 0
    r: 0
    meta:
        shift:
            - 0
            - 0
        rotate: 0
        padding: 19
        width: 1
        height: 1
        skip: false
        asym: both
        name: matrix_middle_bottom
        colrow: middle_bottom
        col: &ref_2
            stagger: 0
            spread: 19
            rotate: 0
            origin:
                - 0
                - 0
            rows: {}
            key: {}
            name: middle
        row: bottom
matrix_middle_home:
    x: 38
    'y': 19
    r: 0
    meta:
        shift:
            - 0
            - 0
        rotate: 0
        padding: 19
        width: 1
        height: 1
        skip: false
        asym: both
        name: matrix_middle_home
        colrow: middle_home
        col: *ref_2
        row: home
matrix_middle_top:
    x: 38
    'y': 38
    r: 0
    meta:
        shift:
            - 0
            - 0
        rotate: 0
        padding: 19
        width: 1
        height: 1
        skip: false
        asym: both
        name: matrix_middle_top
        colrow: middle_top
        col: *ref_2
        row: top
matrix_index_bottom:
    x: 57
    'y': 0
    r: 0
    meta:
        shift:
            - 0
            - 0
        rotate: 0
        padding: 19
        width: 1
        height: 1
        skip: false
        asym: both
        name: matrix_index_bottom
        colrow: index_bottom
        col: &ref_3
            stagger: 0
            spread: 19
            rotate: 0
            origin:
                - 0
                - 0
            rows: {}
            key: {}
            name: index
        row: bottom
matrix_index_home:
    x: 57
    'y': 19
    r: 0
    meta:
        shift:
            - 0
            - 0
        rotate: 0
        padding: 19
        width: 1
        height: 1
        skip: false
        asym: both
        name: matrix_index_home
        colrow: index_home
        col: *ref_3
        row: home
matrix_index_top:
    x: 57
    'y': 38
    r: 0
    meta:
        shift:
            - 0
            - 0
        rotate: 0
        padding: 19
        width: 1
        height: 1
        skip: false
        asym: both
        name: matrix_index_top
        colrow: index_top
        col: *ref_3
        row: top
matrix_inner_bottom:
    x: 76
    'y': 0
    r: 0
    meta:
        shift:
            - 0
            - 0
        rotate: 0
        padding: 19
        width: 1
        height: 1
        skip: false
        asym: both
        name: matrix_inner_bottom
        colrow: inner_bottom
        col: &ref_4
            stagger: 0
            spread: 19
            rotate: 0
            origin:
                - 0
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

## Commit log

2022-01-09 Set up initial process for project. Added 34 key layout for later work.
    [demo.dxf]
2022-02-07 Set up working PCB for Github Actions
2022-02-13 Sent off to allpcb
    [cockamamie-B_Cu.gbr, cockamamie-B_Mask.gbr, cockamamie-B_Paste.gbr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]
2022-03-17 Added rev1 of the board
    [om.kicad_pcb]
2022-03-17 Updated Om silkscreens to look more dynamic
    [om.kicad_pcb]
2022-03-17 Added gerbers
    [om-B_Cu.gbr, om-B_Mask.gbr, om-B_Paste.gbr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]
2022-04-18 Added reversible JST footprint. Added JST / reset jumper to board.
2022-06-19 With the new thumb anchor, closely matched positioning from rev1 PCB.
2022-06-25 Add rev 2 version of board, components are finalized, just need to polish
    [om.kicad_pcb]
2022-06-26 Finished rev2 and added a choc mini variation
    [om.kicad_pcb]
2022-07-01 Fix rev2 cutouts for on / off, add througholes for MCU cover, choc mini now has reversible mini footprints
    [om.kicad_pcb]
2022-07-01 Created gerbers for rev 2 PCB
    [om-B_Cu.gbl, om-B_Mask.gbs, om-B_Paste.gbp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]
2022-07-02 Create the SVGs and DXF for creating the case
    [bottom-layout.dxf]
2022-07-03 Added a couple of cases... may or may not. Waiting on PCBs to arrive to test
    [Om Rev 2 Case v1.stl, Om Rev 2 Case v2.stl, bottom-layout.dxf]
2022-07-03 Move footprints folder to src
2022-07-03 Updated board outline, moved case files
    [Om Rev 2 Case v1.stl, Om Rev 2 Case v2.stl, bottom-layout.dxf]
2022-07-03 Added SVG / DXF of top case components for Fusion 360
    [top.dxf]
2022-11-13 Started on onboard MCU version
    [BA1AAAPC.step, EVQWGD001.step, JST-PH-S2B-R.step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]
2022-11-13 Fix the USB port connections, time to start routing
    [om.kicad_pcb]
2022-11-19 Fix up the schematic -> footprint library usage. Pins were on the wrong pads.
    [om.kicad_pcb, om.kicad_sch]
2022-11-20 Routing might be done?
    [om.kicad_pcb, om.kicad_sch]
2022-12-12 Mostly in place, time to refactor
    [om.csv, om.kicad_pcb, om.kicad_sch]
